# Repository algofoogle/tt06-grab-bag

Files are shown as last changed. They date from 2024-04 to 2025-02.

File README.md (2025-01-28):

 

# Anton's TT06 grab bag

This is a simple analog/mixed-signal project, created from the [TT06 analog template repo](https://github.com/TinyTapeout/tt06-analog-template).

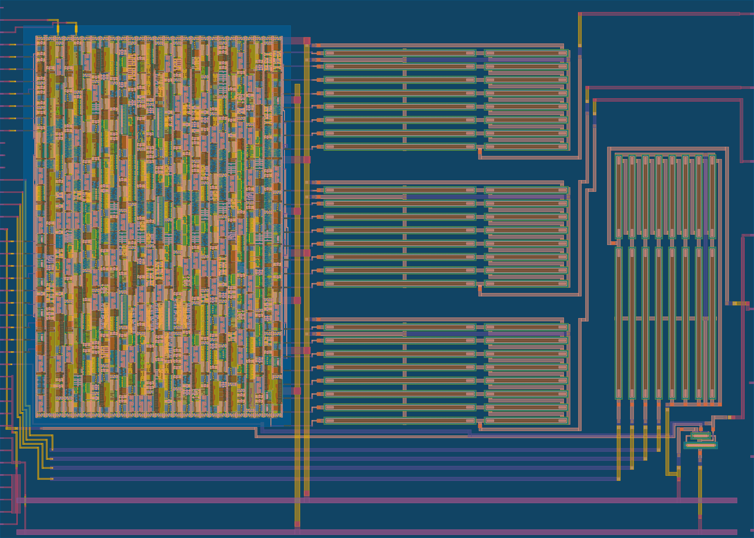
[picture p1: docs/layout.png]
GDS layout render


I was invited to participate in the first round of Matt Venn's Zero to ASIC **Analog Course** beta, and this was the design I ultimately submitted to TT06.

It implements:
*   A digital block that generates a few basic 24b-colour (RGB888) VGA test patterns.
*   Analog RGB outputs (running digital block VGA outputs through 3x 8-bit R2R DACs).
*   An extra 4-bit R2R DAC.
*   A bog-standard CMOS inverter. That was my very first custom layout attempt.

**For much more information, [read the full documentation](docs/info.md)**

See [`pcb/`](./pcb/) for PCBs I've been working on related to this.

# What is Tiny Tapeout?

Tiny Tapeout is an educational project that aims to make it easier and cheaper than ever to get your digital designs manufactured on a real chip.

To learn more and get started, visit https://tinytapeout.com.

# Analog projects

For specifications and instructions, see the [analog specs page](https://tinytapeout.com/specs/analog/).

If you have any questions, please join the [Tiny Tapeout Discord](https://tinytapeout.com/discord) and ask in the `#analog` channel.

# Resources

- [FAQ](https://tinytapeout.com/faq/)
- [Digital design lessons](https://tinytapeout.com/digital_design/)
- [Learn how semiconductors work](https://tinytapeout.com/siliwiz/)
- [Join the community](https://tinytapeout.com/discord)

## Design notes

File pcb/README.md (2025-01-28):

# PCB design files for TT06 Grab Bag

*   [`tt06-vga-opamp/`](./tt06-vga-opamp/) is my original prototyping board that I made for testing tt06-grab-bag. I was originally working on it [here](https://github.com/algofoogle/sandpit/tree/master/opamp/tt06-vga-opamp) (private repo).
*   [`tt06-vga-interposer/`](./tt06-vga-interposer/) is a board I'm working on that sits between the TT06 chip carrier board and the TT06 demo board. It taps the analog signals relevant to this design and buffers them with an OPA3355, and includes a VGA socket.

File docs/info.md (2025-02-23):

<!---
You can also include images in this folder and reference them in the markdown. Each image must be less than
512 kb in size, and the combined size of all images must be less than 1 MB.

NOTE: I've used &#126; instead of actual `~` to avoid a mismatch between GFM and the PDF doc generation
(i.e. GFM sees this character as a strikethrough marker, but the PDF doc generation does not).
Note that `~` while commonly called a tilde is actually the "equivalency sign" (tilde is up high).
Ideally I would use &#x2053 ('swung dash') which is technically probably the correct symbol for
"approximate ranges" but this doesn't work in the PDF generator.
-->

tt06-grab-bag GDS layout showing digital block, 4 DACs, and 1 inverter

## What is this thing?

<!-- <img src="layout-portrait.png" style="float: right; margin-left: 1em;" width="40%" /> -->

A simple analog/mixed-signal project I created in the 1st round of Matt Venn's Zero to ASIC **Analog Course** beta. **This design has been demonstrated to work in silicon.** For silicon test results, see my journal entry: https://algo.org/journal/0226

The design comprises:

*   Simple CMOS inverter. That was my very first custom layout attempt.
*   Digital block generating a few basic 24b-colour (RGB888) VGA test patterns.
*   Analog RGB out (digital block VGA outputs via 3x 8-bit R2R DACs).
*   An extra 4-bit R2R DAC.

## VGA test pattern outputs

The design's *main* purpose is to generate VGA test patterns that were hoped to look as good as these simulations:

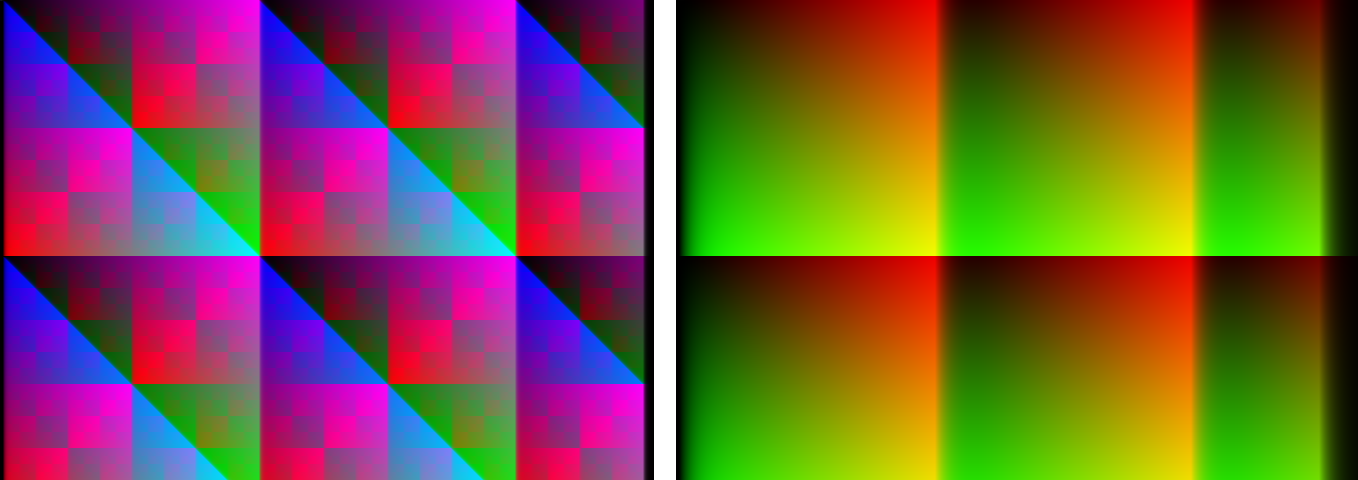
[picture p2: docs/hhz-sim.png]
Simulated VGA outputs, XOR pattern and RAMP pattern


The left-hand pretty pattern is "MODE_XORS" (`ui_in==8'b0011_0000`) while the right-hand gradients pattern is "MODE_RAMP" (`ui_in==8'b0001_0000`).

Notice there is some horizontal smearing (more exaggerated in the right-hand image of the red/green mixes).

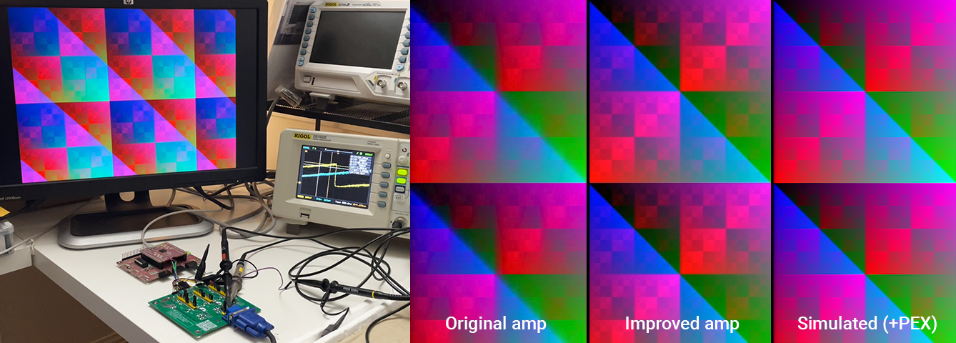
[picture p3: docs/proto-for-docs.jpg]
Real silicon, working, driving a VGA monitor


Actual results from silicon testing (seen above) are pleasing.

## CMOS inverter

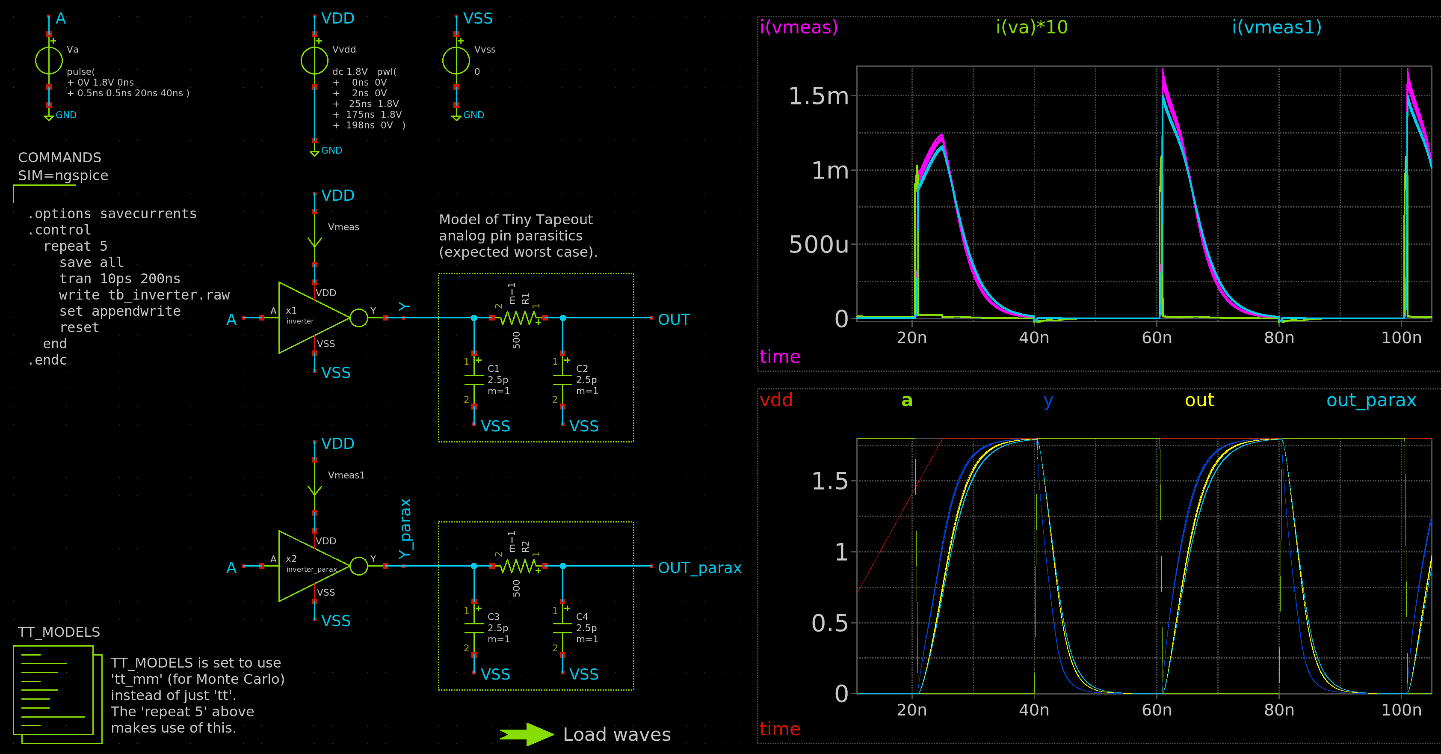
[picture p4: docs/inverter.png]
Xschem simulation of my CMOS inverter


Pretty simple:

*   Its input is `uio_in[7]` (bidir 7).
*   Its output goes to two places: `ua[3]` (analog) and `uio_out[2]` (digital).
*   I'd expect its digital out performance to be better: the TT digital mux has more buffering & less loading than the TT analog mux.

The graphs accompanying the schematics simulate *analog* out is expected to be stable (enough) within 10ns; relatively poor performance characteristic of the TT analog mux loading. I expect bigger transistors could drive this harder and make it faster.

## Extra 4-bit R2R

4th instance of my 8-bit R2R DAC cell grounds the 4 LSB, connecting the 4 MSB to spare bidir inputs (`uio_in[6:4]`) with DAC output via `ua[4]`.

## How it works

TBC!

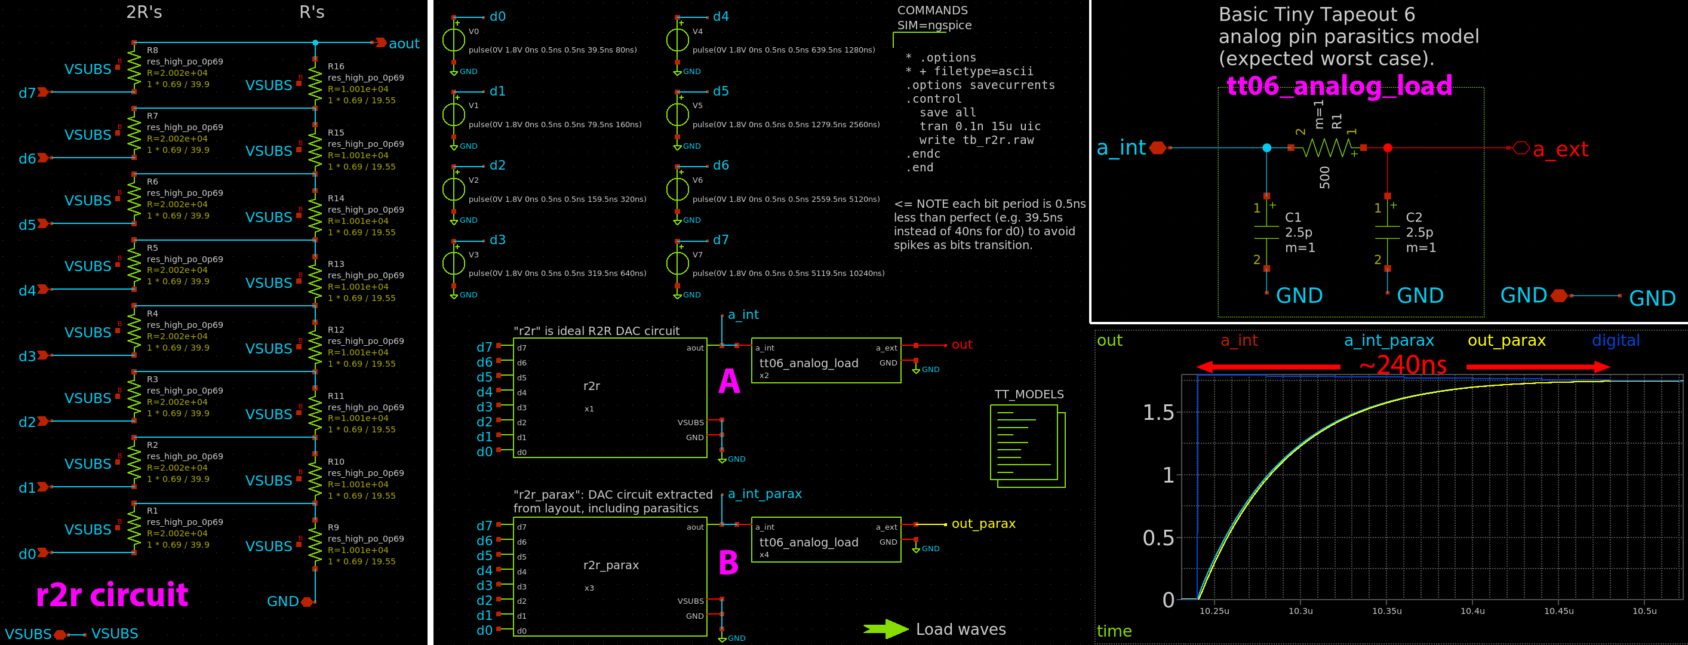
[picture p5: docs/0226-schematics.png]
Combined VGA DACs schematics


The internal R2R DACs for each of the RGB outputs just go directly (unbuffered) to the analog output pins, where they are subject to the loading of the TT06 analog mux (estimated to be about 500&ohm; and 5pF). This combination means their slew rate was expected to be pretty bad (at least by VGA timing standards): On the order of 240&#126;360ns (or 6&#126;9 horizontal pixels) going from 0V to full 1.8V. In the chips I received, it was a little better than that.

In a future design I plan to implement better internal buffering to help mitigate some of the TT analog mux load.

Select from a few simple test patterns in the VGA controller by having different `ui_in` values asserted while coming out of reset. the VGA controller digital block generates 8-bit digital outputs per each of red, green, and blue channels. These go into 3 basic RDACs to generate analog voltage outputs on `ua[2:0]` (`{B,G,R}`) in the range 0-1.8V (probably &#126;10k&ohm; impedance).

## How to test

TBC!

1.  Supply a 25MHz clock
2.  Set `ui_in` to `8'b0001_0000`
3.  Assert reset -- NOTE: I didn't put a synchroniser on it, so it might (?) do a dirty reset -- if that happens, it could be worked around by slowly/manually clocking around the reset pulse, I guess.
4.  With a scope, trigger on the `uo_out[3]` rising edge (VSYNC) and hopefully see `ua[0]` ramp from 0V to 1.8V within 10.24us
5.  With this mode (as selected in step 2 above), `ua[1]` will also ramp, but per line (instead of per pixel), as will `ua[2]` (per frame).
6.  For the pretty XORs pattern, set `ui_in` to `8'b0011_0000` and assert reset again.

NOTE: For actual VGA output, you need the VSYNC and HSYNC signals (connecting them each with a 1k&ohm; resistor in series with their respective VGA cable connection should do). You will almost certainly need some sort of output buffering between this design and a VGA display, because the design outputs a high-impedance (&#126;10k&ohm; but maybe a little worse) 0&#126;1.8V range, while a VGA display expects 0&#126;0.7V at 75&ohm;. See https://algo.org/pcb/tt06i for an example board that covers all this.

Other notes for testing:

*   Digital block's mode selection is asserted via `ui_in` *during reset*
*   For safety, initial test should be done with no analog output loading, and with all of `ui_in` pulled low (which selects pass-thru mode AND ensures all DAC *inputs* internally are low, so hopefully no current).
*   RGB222 digital outputs compatible with the [Tiny VGA PMOD].

## External hardware

This is if you want to see an actual analog VGA display:

*   10MHz-capable (or better; preferably 25MHz) opamps on each of the R, G, B outputs, to both make them into low-impedance (matching 75&ohm; typical VGA termination), and also to level-shift from 0&#126;1.8V to 0&#126;0.7V. See https://algo.org/pcb/tt06i for an example "interposer board" (aka "sandwich board") which uses an OPA3355 video op-amp circuit with VGA connector, and is intended to sit between the TT06 chip's breakout board (aka "carrier") and the TT06 demo board.
*   Optionally the [Tiny VGA PMOD] plugged into the dedicated output port (`uo_out`).

[Tiny VGA PMOD]: https://github.com/mole99/tiny-vga

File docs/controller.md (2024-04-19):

# Controller

## Pinouts

### `ui_in`

*   **DONE:** See detailed info below about reset state

### `uo_out`

These match the Tiny VGA PMOD - See: https://github.com/algofoogle/tt05-vga-spi-rom/blob/9208ed836d03bb5593d383a55a8ddcab464ed9d2/src/tt05_top.v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

0.  **DONE**: `red[7]`
1.  **DONE**: `green[7]`
2.  **DONE**: `blue[7]`
3.  **DONE**: `vsync`
4.  **DONE**: `red[6]`
5.  **DONE**: `green[6]`
6.  **DONE**: `blue[6]`
7.  **DONE**: `hsync`

### `ua`

0.  **DONE:** `red`
1.  **DONE:** `green`
2.  **DONE:** `blue`
3.  **DONE (nil):** (none)
4.  **DONE (nil):** (none)
5.  **DONE**: `Y` (inverter output)

### bidir

0.  **DONE:** OUT: vblank
1.  **DONE:** OUT: hblank
2.  **DONE:** OUT: `Y` (copy of inverter output)
3.  **DONE (nil):** (IN: unused)
4.  **DONE (nil):** (IN: unused)
5.  **DONE (nil):** (IN: unused)
6.  **DONE (nil):** (IN: unused)
7.  **DONE:** IN: `A` (inverter input)

`uio_oe` ties:

0.  **DONE:** *VPWR*
1.  **DONE:** *VPWR*
2.  **DONE:** *VPWR*
3.  **DONE:** VGND
4.  **DONE:** VGND
5.  **DONE:** VGND
6.  **DONE:** VGND
7.  **DONE:** *VPWR*

`uio_out` ties:

3.  **DONE:** VGND
4.  **DONE:** VGND
5.  **DONE:** VGND
6.  **DONE:** VGND
7.  **DONE:** VGND

### Power

*   Controller:
    *   **DONE:** VPWR
    *   **DONE:** VGND
*   DACs:
    *   **DONE:** VGND
    *   **DONE:** VSUBS
*   Inverter:
    *   **DONE:** VPWR (VDD)
    *   **DONE:** VGND (VSS)

## Info

Pin arrangement:

*   North:
    *   TT pin pitch is 3.68um
*   South:
    *   DAC pin pitch is 4um
    *   Insert dummy pins between channels

This is part of an intended mixed-signal design. Not properly implemented yet.

```

Mode selected by ui_in at reset:

Bit 7 specifies VGA timing selection:
    0 = Regular 640x480@59.94Hz from 25.175MHz clock
    1 = 1440x900@60Hz from 26.6175MHz clock

Mode 0: Pass ui_in directly to all 3 DACs:
    76543210
    -000----    Mode
    ------g-    Gate: 0 = ungated; 1 = gated by VGA blanking
    -------r    Registered: 0 = unregistered; 1 = registered

Mode 1: Ramp tests:
    -001----    Mode
    ----dd--    Divider (-1, i.e. 0=div/1, 1=div/2)
    ------pp    Primary:
                0 = red
                1 = green
                2 = blue
                4 = all

Mode 2: Bars test: Ramp interleaved with negative ramp on alternate pixels
    -010----    Mode
    ----dd--    Divider (-1, i.e. 0=div/1, 1=div/2)
    ------pp    Primary:
                0 = red
                1 = green
                2 = blue
                4 = all

Mode 3: XOR patterns
...SEE BELOW...
```

For nice XOR patterns, this Shadertoy code gives an idea of something cool that we can do:

```c
void mainImage( out vec4 fragColor, in vec2 fragCoord )
{
    // Normalized pixel coordinates (from 0 to 1)
    vec2 uv = fragCoord/iResolution.xy;
    
    int t = int(iTime*60.0) & 0xFF;
    int x = int(fragCoord.x) & 0xFF;
    int y = int(fragCoord.y) & 0xFF;
    int ax = (((int(fragCoord.x)+int(iTime*7.5))>>1) & 0xFF);
    int ay = (((int(fragCoord.y)+int(iTime*7.5))>>1) & 0xFF);
    int bx = (((int(fragCoord.x)+int(iTime*15.0))<<0) & 0xFF);
    int by = (((int(fragCoord.y)+int(iTime*30.0))<<0) & 0xFF);
    int cx = (((int(fragCoord.x)+int(iTime*30.0))<<1) & 0xFF);
    int cy = (((int(fragCoord.y)+int(iTime*15.0))<<1) & 0xFF);

    vec3 col;
    if (false) {    
        // Time varying pixel color
        col = vec3(
            float(ax^ay)/256.0,
            float(bx^by)/256.0,
            float(cx^cy)/256.0
        ); //0.5 + 0.5*cos(iTime+uv.xyx+vec3(0,2,4));
    } else {    
        col = vec3(
            float(0xFF&((x>>1)^((y<<0))))/256.0,
            float(0xFF&(x&y))/256.0,
            float(0xFF&(((x-y)&0xFF)+(t&0xFF)/*^(y^x)*/))/256.0
        );
    }

    // Output to screen
    fragColor = vec4(col,1.0);
}
```

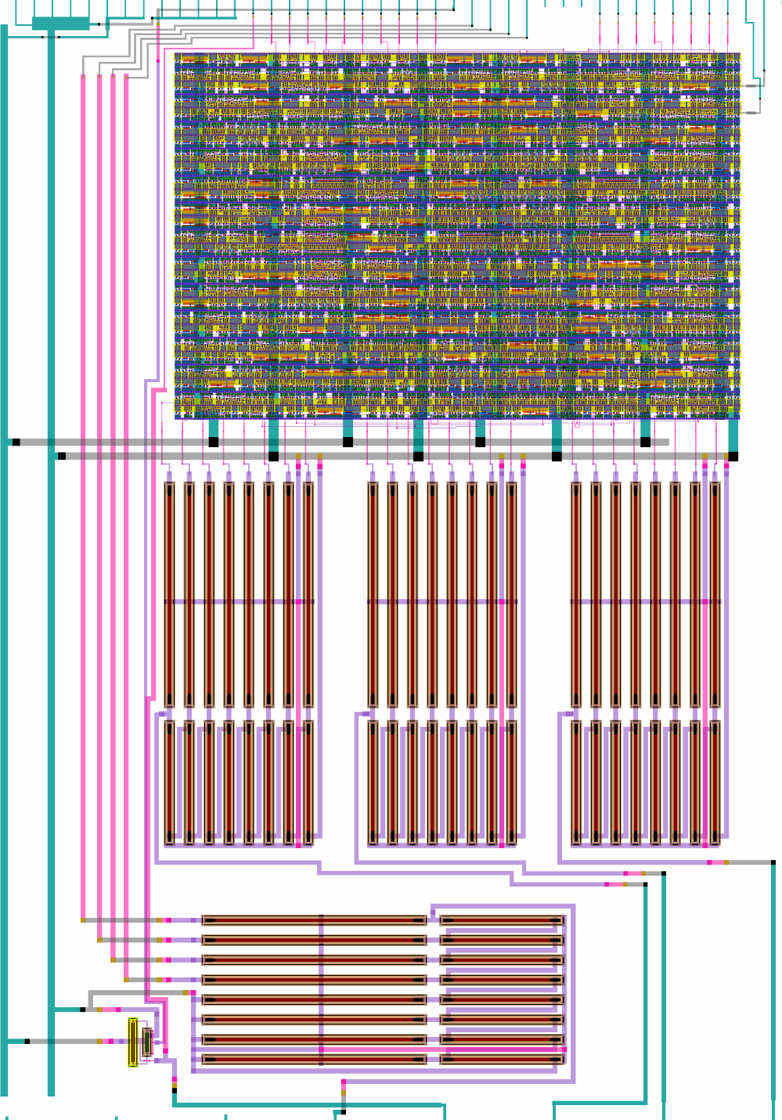
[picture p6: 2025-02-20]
mag/mag-render.png

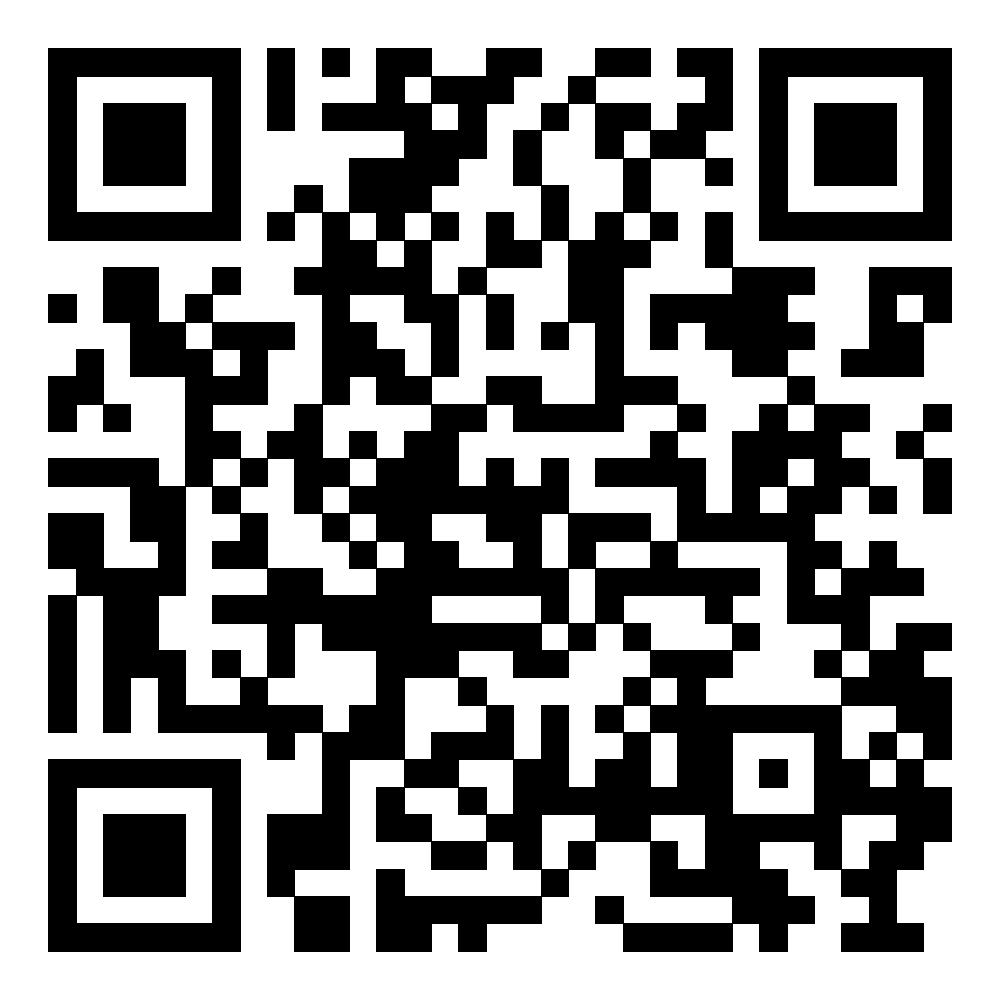
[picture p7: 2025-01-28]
pcb/tt06-vga-opamp/tt06a-qr.png

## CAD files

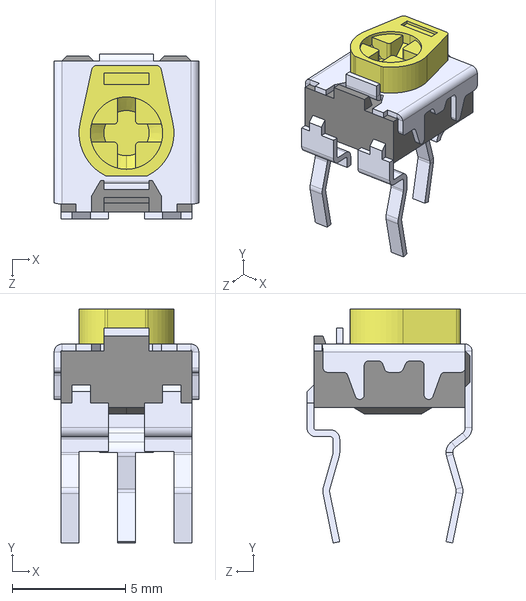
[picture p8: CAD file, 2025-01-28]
pcb/tt06-vga-interposer/3d/EVN_D8AA03B55/EVN-D8AA03B55.step
6.40 x 10.4 x 7.30 mm

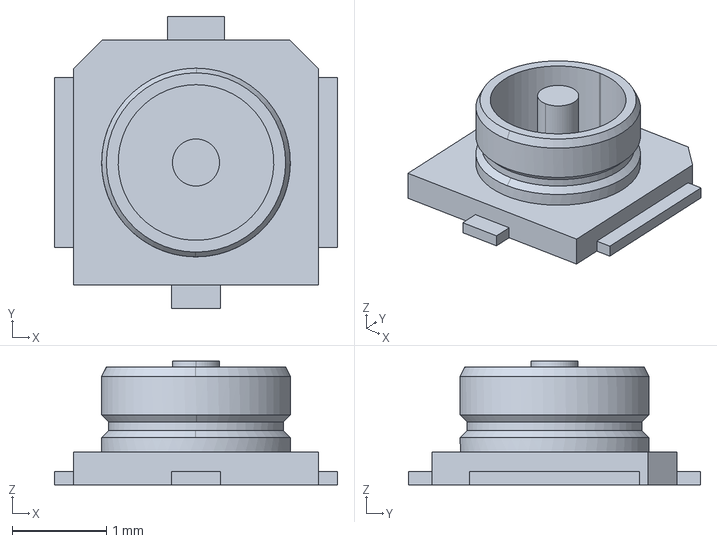
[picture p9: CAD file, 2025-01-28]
pcb/tt06-vga-opamp/U.FL-connector/CONMHF1-SMD-G-T.step
3.00 x 3.10 x 1.31 mm

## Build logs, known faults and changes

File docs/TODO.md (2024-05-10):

*   How to safely probe
*   Input impedance of LM741 and other newer opamps
*   Design PCB base board that fits the carrier -- might need a Pi Pico both for selecting the design, clocking it, and sampling outputs via ADC. Intent of this board is not only for my testing, but also hacking on (if I want to try different core voltage, for example, or doing current limiting) and having an actual VGA output.
*   Pi Pico could clock the design at a slow speed, sample outputs, then gradually speed it up and see how well it performs. Generate images via streaming to PC.
*   Output impedance from the design: Test with a 100k resistor?
*   Simulations:
    *   "Reference image": What it would look like with perfect 24-bit digital output
    *   Just the analog part
    *   Analog part from extraction -- just delete the digital block and re-extract?
    *   Whole extracted layout (using SPICE model for the digital part too) -- will be VERY slow
    *   Cosim
    *   Cosim with an extra Verilog wrapper to provide inputs.

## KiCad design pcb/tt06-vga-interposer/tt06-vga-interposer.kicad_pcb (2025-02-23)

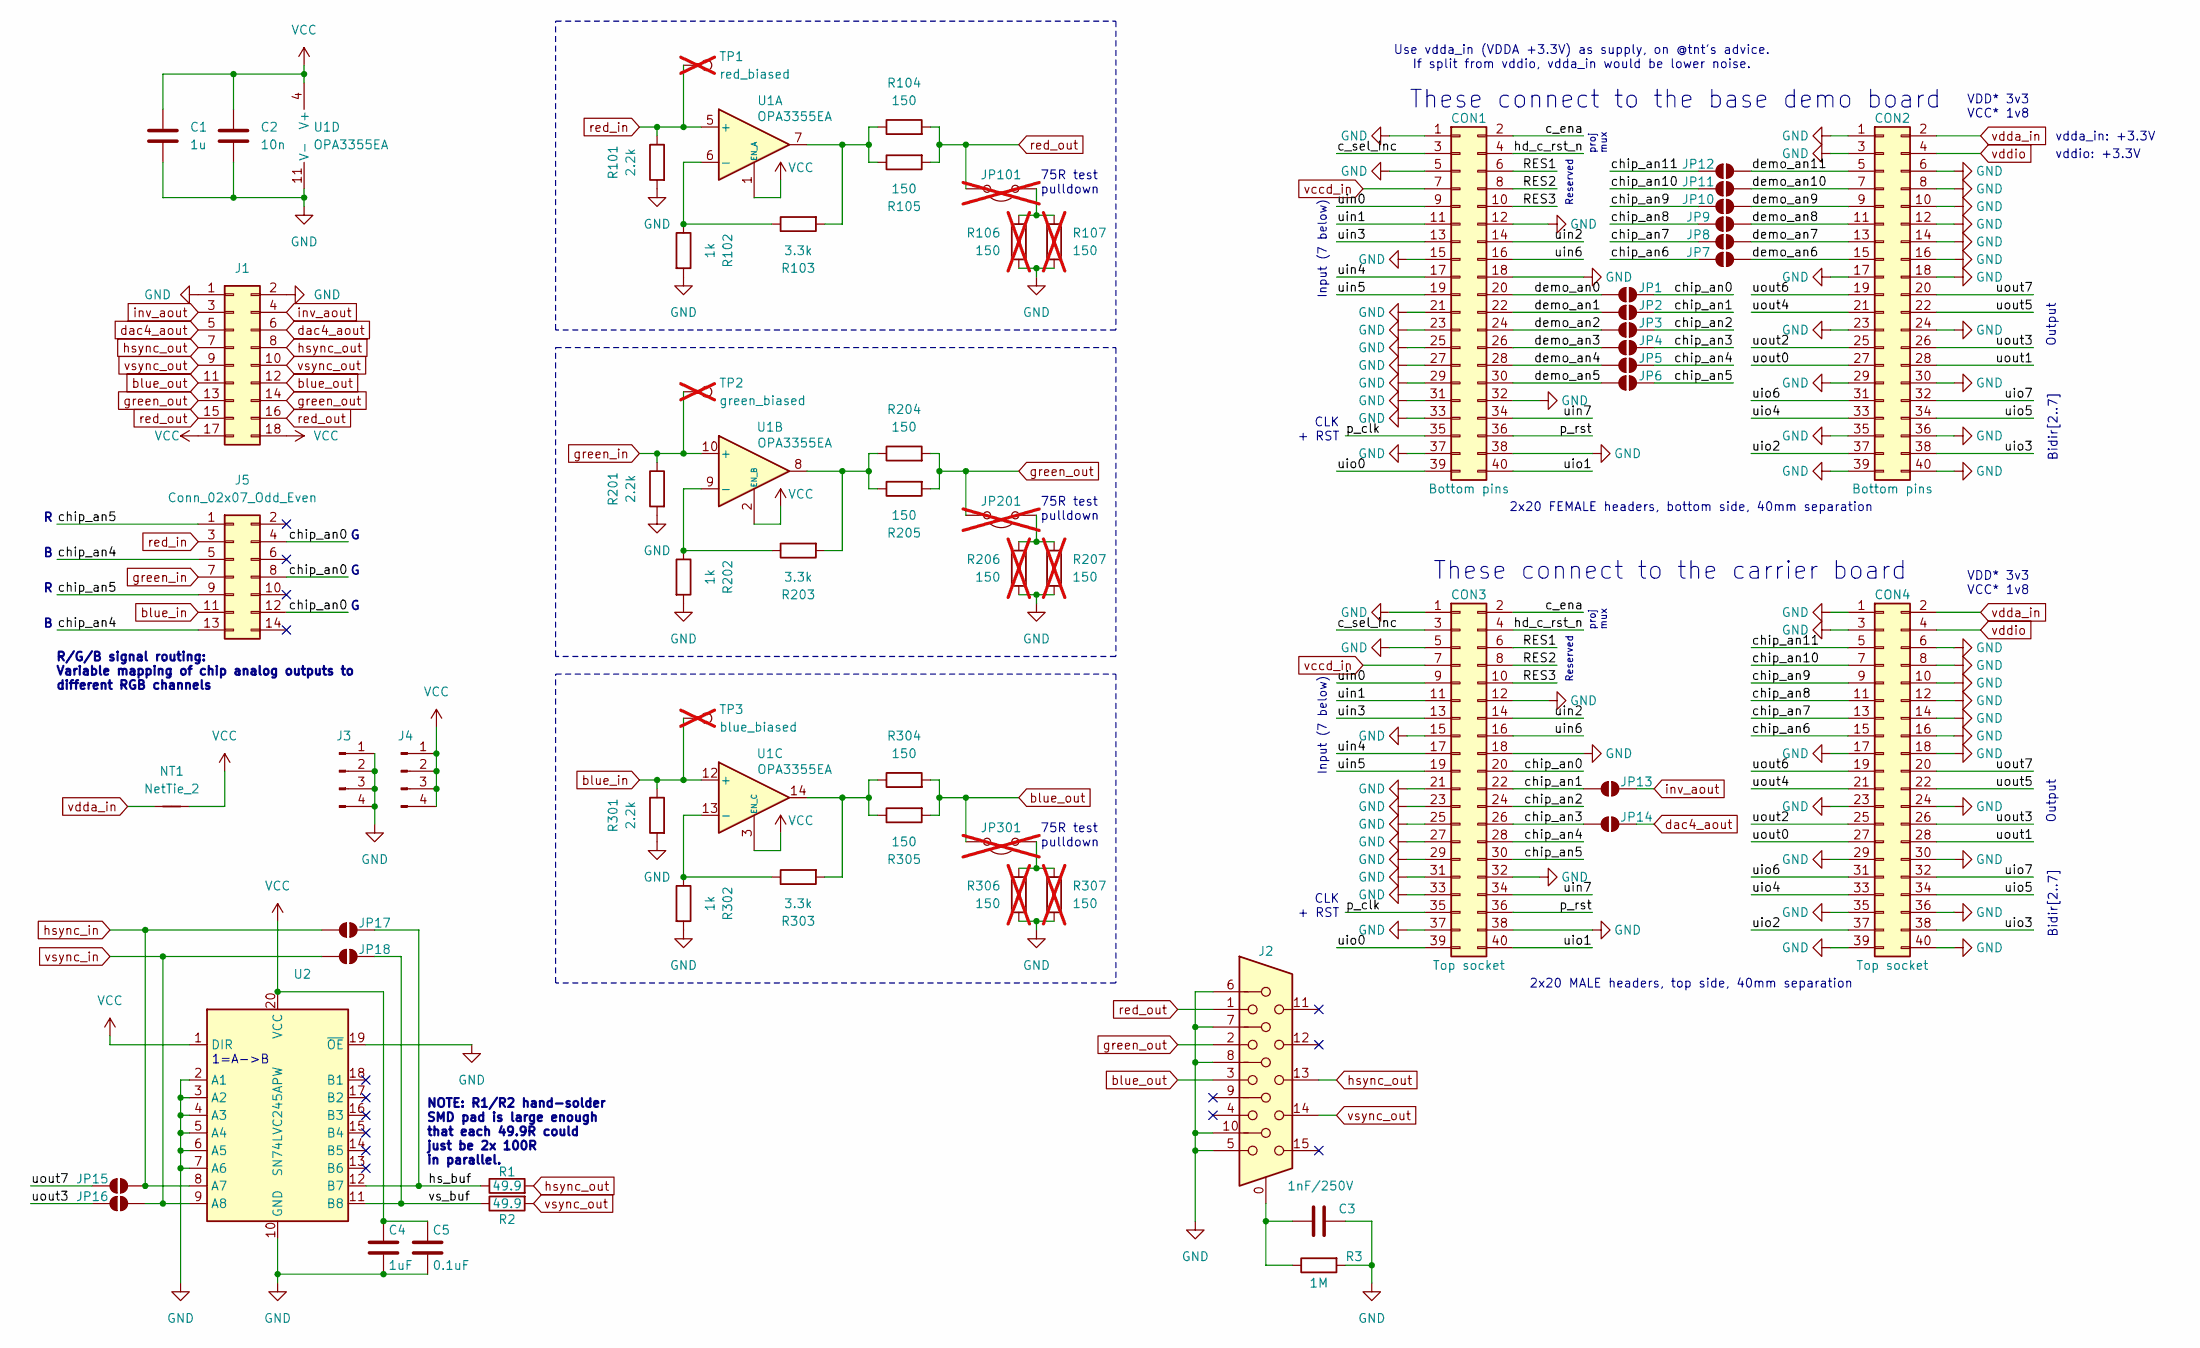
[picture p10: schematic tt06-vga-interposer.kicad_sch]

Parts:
C1: 1u; SMD_Passive_HandSolder_0603_to_1210
C2: 10n; SMD_Passive_HandSolder_0603_to_1210
C3: 1nF/250V; SMD_Passive_HandSolder_0603_to_1210
C4: 1uF; SMD_Passive_HandSolder_0603_to_1210
C5: 0.1uF; SMD_Passive_HandSolder_0603_to_1210
CON1, CON2: Bottom pins; PinSocket_2x20_P2.54mm_Vertical; MPN NPTC202KFMS-RC; DigikeyPN S5690-ND
CON3, CON4: Top socket; PinHeader_2x20_P2.54mm_Vertical; MPN NPTC202KFMS-RC; DigikeyPN S5690-ND
J1: Conn_02x09_Odd_Even; PinHeader_2x09_P2.54mm_Vertical
J2: DE15_Receptacle_HighDensity_MountingHoles; DSUB-15-HD_F_Horz_P2.29x2.54mm_EPO3.03mm_MO4.94mm_STRONG
J3, J4: Conn_01x04_Pin; PinHeader_1x04_P2.54mm_Vertical
J5: Conn_02x07_Odd_Even; PinHeader_2x07_P2.54mm_Horizontal
JP1, JP2, JP3, JP4, JP5, JP6, JP7, JP8, JP9, JP10, JP11, JP12, JP13, JP14, JP15, JP16, JP17, JP18: SolderJumper_2_Open; SolderJumper-2_tiny_nomask
JP101, JP201, JP301: Jumper_2_Open; PinHeader_2x01_P2.54mm_Vertical; not fitted
NT1: NetTie_2; NetTie-2_SMD_Pad0.5mm
R1, R2: 49.9; SMD_Passive_HandSolder_0603_to_1210
R3: 1M; SMD_Passive_HandSolder_0603_to_1210
R101, R201, R301: 2.2k; SMD_Passive_HandSolder_0603_to_1210
R102, R202, R302: 1k; SMD_Passive_HandSolder_0603_to_1210
R103, R203, R303: 3.3k; SMD_Passive_HandSolder_0603_to_1210
R104, R105, R204, R205, R304, R305: 150; SMD_Passive_HandSolder_0603_to_1210
R106, R107, R206, R207, R306, R307: 150; SMD_Passive_HandSolder_0603_to_1210; not fitted
TP1: red_biased; PinHeader_1x01_P2.54mm_Vertical; not fitted
TP2: green_biased; PinHeader_1x01_P2.54mm_Vertical; not fitted
TP3: blue_biased; PinHeader_1x01_P2.54mm_Vertical; not fitted
U1: OPA3355EA; TSSOP-14_4.4x5mm_P0.65mm_HandSolder
U2: SN74LVC245APW; TSSOP-20_4.4x6.5mm_P0.65mm_HandSolder

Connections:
/RES1: CON1.6, CON3.6
/RES2: CON1.8, CON3.8
/RES3: CON1.10, CON3.10
/c_ena: CON1.2, CON3.2
/c_sel_inc: CON1.3, CON3.3
/chip_an0: CON3.20, J5.4, J5.8, J5.12, JP1.2 (B)
/chip_an1: CON3.22, JP2.2 (B), JP13.1 (A)
/chip_an2: CON3.24, JP3.2 (B)
/chip_an3: CON3.26, JP4.2 (B), JP14.1 (A)
/chip_an4: CON3.28, J5.5, J5.13, JP5.2 (B)
/chip_an5: CON3.30, J5.1, J5.9, JP6.2 (B)
/chip_an6: CON4.15, JP7.2 (B)
/chip_an7: CON4.13, JP8.2 (B)
/chip_an8: CON4.11, JP9.2 (B)
/chip_an9: CON4.9, JP10.2 (B)
/chip_an10: CON4.7, JP11.2 (B)
/chip_an11: CON4.5, JP12.2 (B)
/demo_an0: CON1.20, JP1.1 (A)
/demo_an1: CON1.22, JP2.1 (A)
/demo_an2: CON1.24, JP3.1 (A)
/demo_an3: CON1.26, JP4.1 (A)
/demo_an4: CON1.28, JP5.1 (A)
/demo_an5: CON1.30, JP6.1 (A)
/demo_an6: CON2.15, JP7.1 (A)
/demo_an7: CON2.13, JP8.1 (A)
/demo_an8: CON2.11, JP9.1 (A)
/demo_an9: CON2.9, JP10.1 (A)
/demo_an10: CON2.7, JP11.1 (A)
/demo_an11: CON2.5, JP12.1 (A)
/hd_c_rst_n: CON1.4, CON3.4
/hs_buf: JP17.2 (B), R1.1, U2.12 (B7)
/p_clk: CON1.35, CON3.35
/p_rst: CON1.36, CON3.36
/uin0: CON1.9, CON3.9
/uin1: CON1.11, CON3.11
/uin2: CON1.14, CON3.14
/uin3: CON1.13, CON3.13
/uin4: CON1.17, CON3.17
/uin5: CON1.19, CON3.19
/uin6: CON1.16, CON3.16
/uin7: CON1.34, CON3.34
/uio0: CON1.39, CON3.39
/uio1: CON1.40, CON3.40
/uio2: CON2.37, CON4.37
/uio3: CON2.38, CON4.38
/uio4: CON2.33, CON4.33
/uio5: CON2.34, CON4.34
/uio6: CON2.31, CON4.31
/uio7: CON2.32, CON4.32
/uout0: CON2.27, CON4.27
/uout1: CON2.28, CON4.28
/uout2: CON2.25, CON4.25
/uout3: CON2.26, CON4.26, JP16.2 (B)
/uout4: CON2.21, CON4.21
/uout5: CON2.22, CON4.22
/uout6: CON2.19, CON4.19
/uout7: CON2.20, CON4.20, JP15.2 (B)
/vs_buf: JP18.2 (B), R2.1, U2.11 (B8)
GND: C1.2, C2.2, C3.2, C4.2, C5.2, CON1.1, CON1.5, CON1.12, CON1.15, CON1.18, CON1.21, CON1.23, CON1.25, CON1.27, CON1.29, CON1.31, CON1.32, CON1.33, CON1.37, CON1.38, CON2.1, CON2.3, CON2.6, CON2.8, CON2.10, CON2.12, CON2.14, CON2.16, CON2.17, CON2.18, CON2.23, CON2.24, CON2.29, CON2.30, CON2.35, CON2.36, CON2.39, CON2.40, CON3.1, CON3.5, CON3.12, CON3.15, CON3.18, CON3.21, CON3.23, CON3.25, CON3.27, CON3.29, CON3.31, CON3.32, CON3.33, CON3.37, CON3.38, CON4.1, CON4.3, CON4.6, CON4.8, CON4.10, CON4.12, CON4.14, CON4.16, CON4.17, CON4.18, CON4.23, CON4.24, CON4.29, CON4.30, CON4.35, CON4.36, CON4.39, CON4.40, J1.1, J1.2, J2.5, J2.6, J2.7, J2.8, J2.10, J3.1, J3.2, J3.3, J3.4, R3.2, R101.2, R102.2, R106.1, R107.1, R201.2, R202.2, R206.1, R207.1, R301.2, R302.2, R306.1, R307.1, U1.11 (V-), U2.2 (A1), U2.3 (A2), U2.4 (A3), U2.5 (A4), U2.6 (A5), U2.7 (A6), U2.10 (GND), U2.19 (~OE)
unnamed: C3.1, J2.0, R3.1
unnamed: JP101.2 (B), R106.2, R107.2
unnamed: JP201.2 (B), R206.2, R207.2
unnamed: JP301.2 (B), R306.2, R307.2
unnamed: R103.2, R104.1, R105.1, U1.7
unnamed: R203.2, R204.1, R205.1, U1.8
unnamed: R303.2, R304.1, R305.1, U1.14
unnamed: R102.1, R103.1, U1.6 (-)
unnamed: R202.1, R203.1, U1.9 (-)
unnamed: R302.1, R303.1, U1.13 (-)
VCC: C1.1, C2.1, C4.1, C5.1, J1.17, J1.18, J4.1, J4.2, J4.3, J4.4, NT1.1, U1.1 (EN_A), U1.2 (EN_B), U1.3 (EN_C), U1.4 (V+), U2.1 (DIR), U2.20 (VCC)
blue_in: J5.11, R301.1, TP3.1, U1.12 (+)
blue_out: J1.11, J1.12, J2.3, JP301.1 (A), R304.2, R305.2
dac4_aout: J1.5, J1.6, JP14.2 (B)
green_in: J5.7, R201.1, TP2.1, U1.10 (+)
green_out: J1.13, J1.14, J2.2, JP201.1 (A), R204.2, R205.2
hsync_in: JP15.1 (A), JP17.1 (A), U2.8 (A7)
hsync_out: J1.7, J1.8, J2.13, R1.2
inv_aout: J1.3, J1.4, JP13.2 (B)
red_in: J5.3, R101.1, TP1.1, U1.5 (+)
red_out: J1.15, J1.16, J2.1, JP101.1 (A), R104.2, R105.2
vccd_in: CON1.7, CON3.7
vdda_in: CON2.2, CON4.2, NT1.2
vddio: CON2.4, CON4.4
vsync_in: JP16.1 (A), JP18.1 (A), U2.9 (A8)
vsync_out: J1.9, J1.10, J2.14, R2.2

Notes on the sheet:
Output
proj mux
Use vdda_in (VDDA +3.3V) as supply, on @tnt's advice. If split from vddio, vdda_in would be lower noise.
VDD* 3v3 VCC* 1v8
vdda_in: +3.3V
Reserved
75R test pulldown
These connect to the carrier board
2x20 FEMALE headers, bottom side, 40mm separation
Input (7 below)
2x20 MALE headers, top side, 40mm separation
vddio: +3.3V
R/G/B signal routing: Variable mapping of chip analog outputs to different RGB channels
NOTE: R1/R2 hand-solder SMD pad is large enough that each 49.9R could just be 2x 100R in parallel.
Bidir[2..7]
These connect to the base demo board
1=A->B
CLK + RST

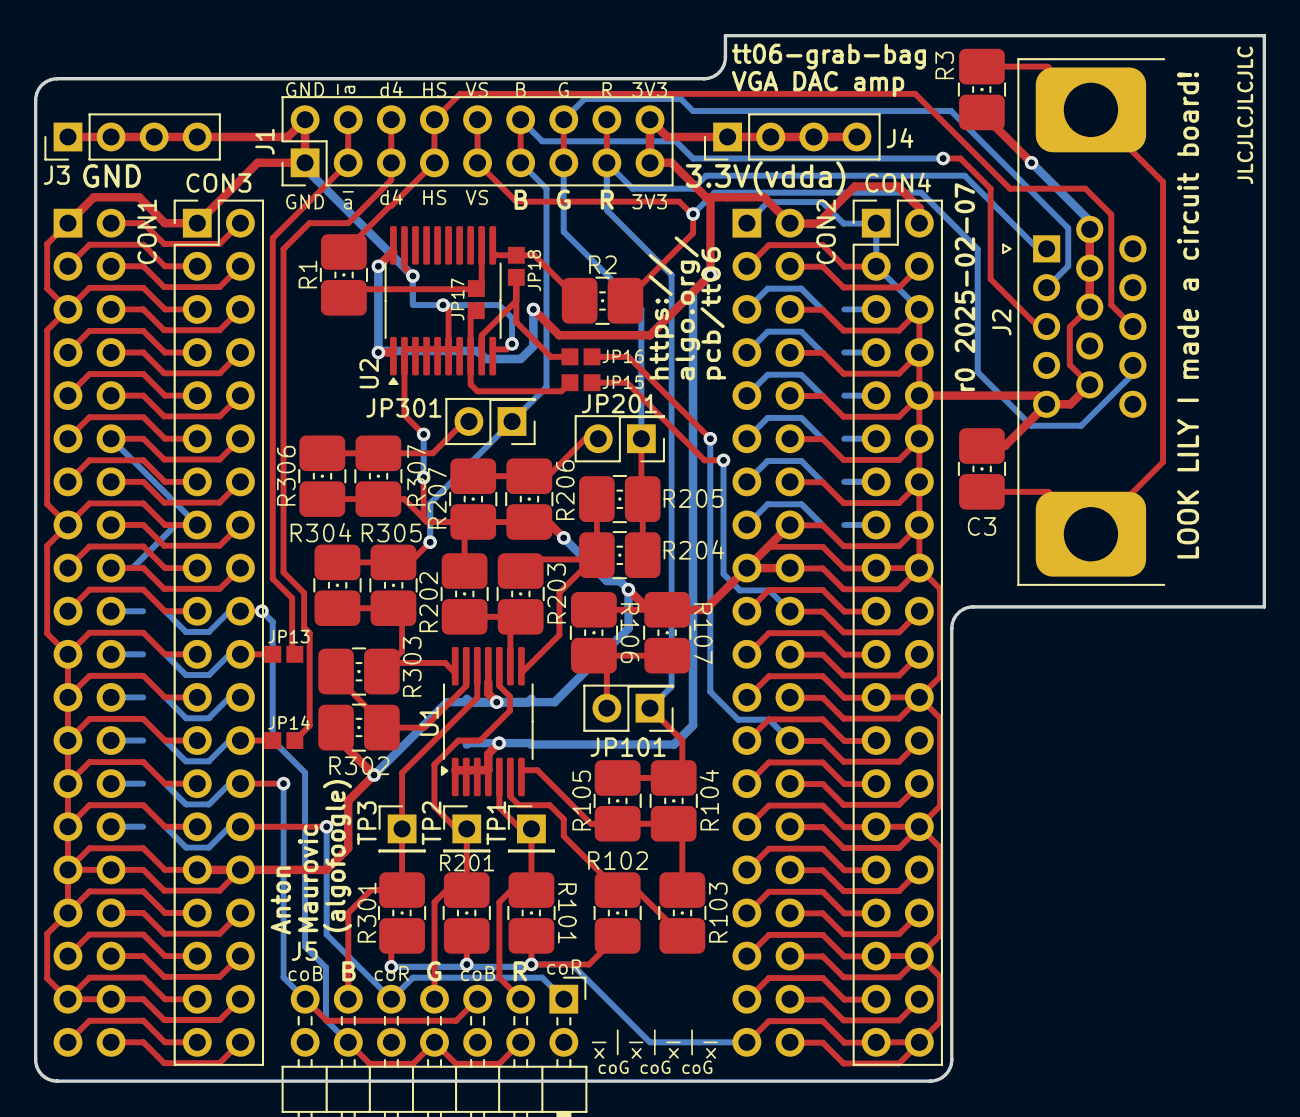
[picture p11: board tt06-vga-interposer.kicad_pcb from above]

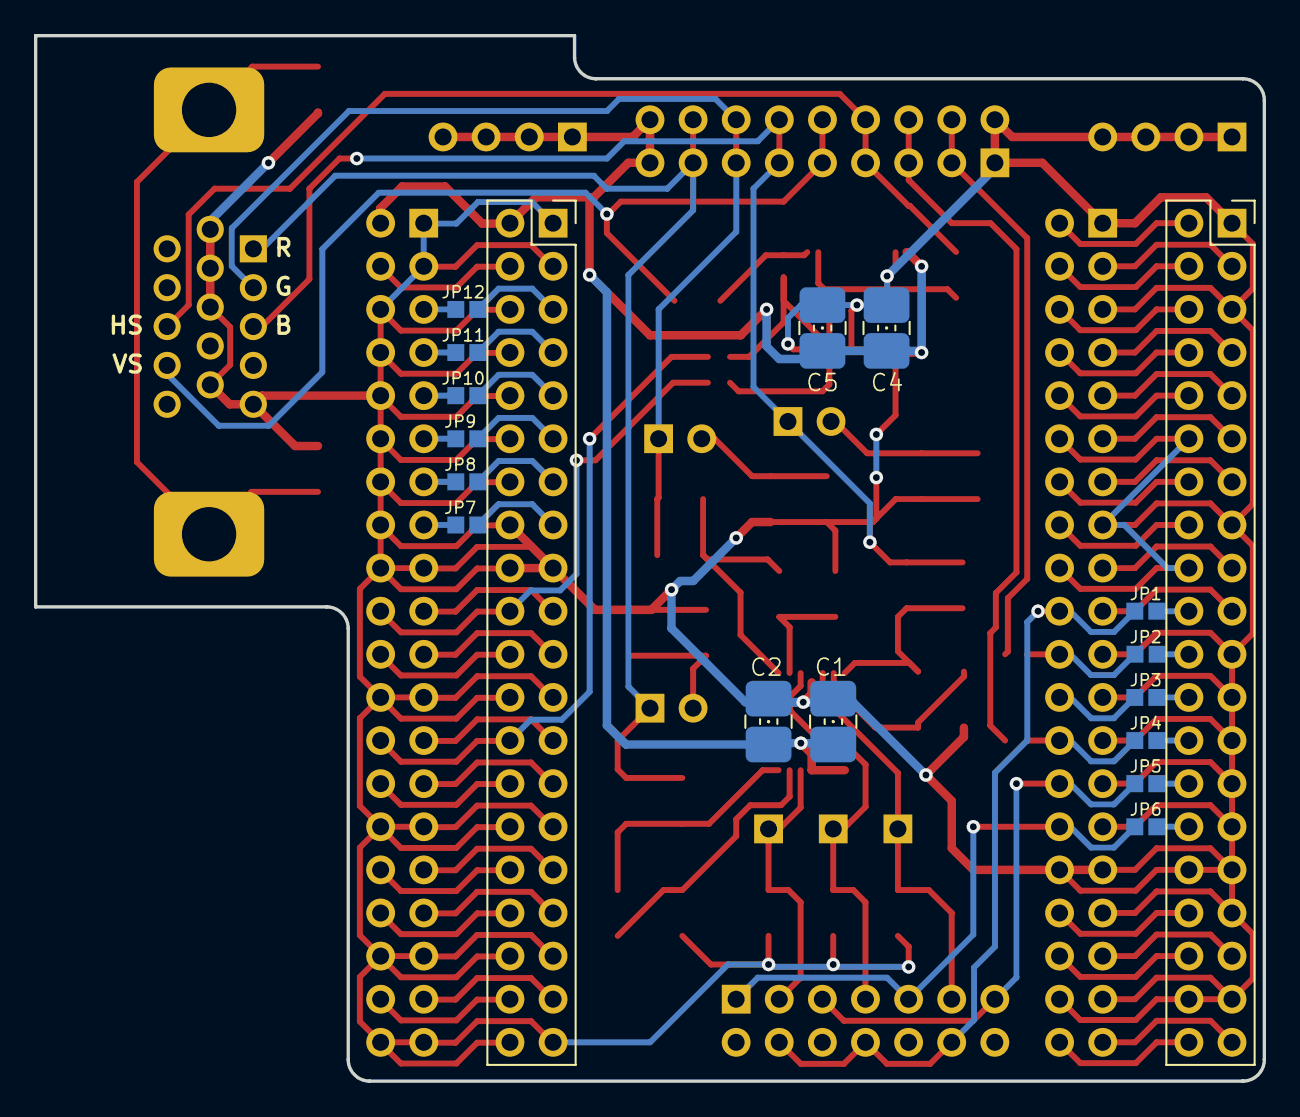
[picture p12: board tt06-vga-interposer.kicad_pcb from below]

Board: 2 copper layers, 72.4 x 61.6 mm, 65 parts (18 on the bottom side), 85 nets.

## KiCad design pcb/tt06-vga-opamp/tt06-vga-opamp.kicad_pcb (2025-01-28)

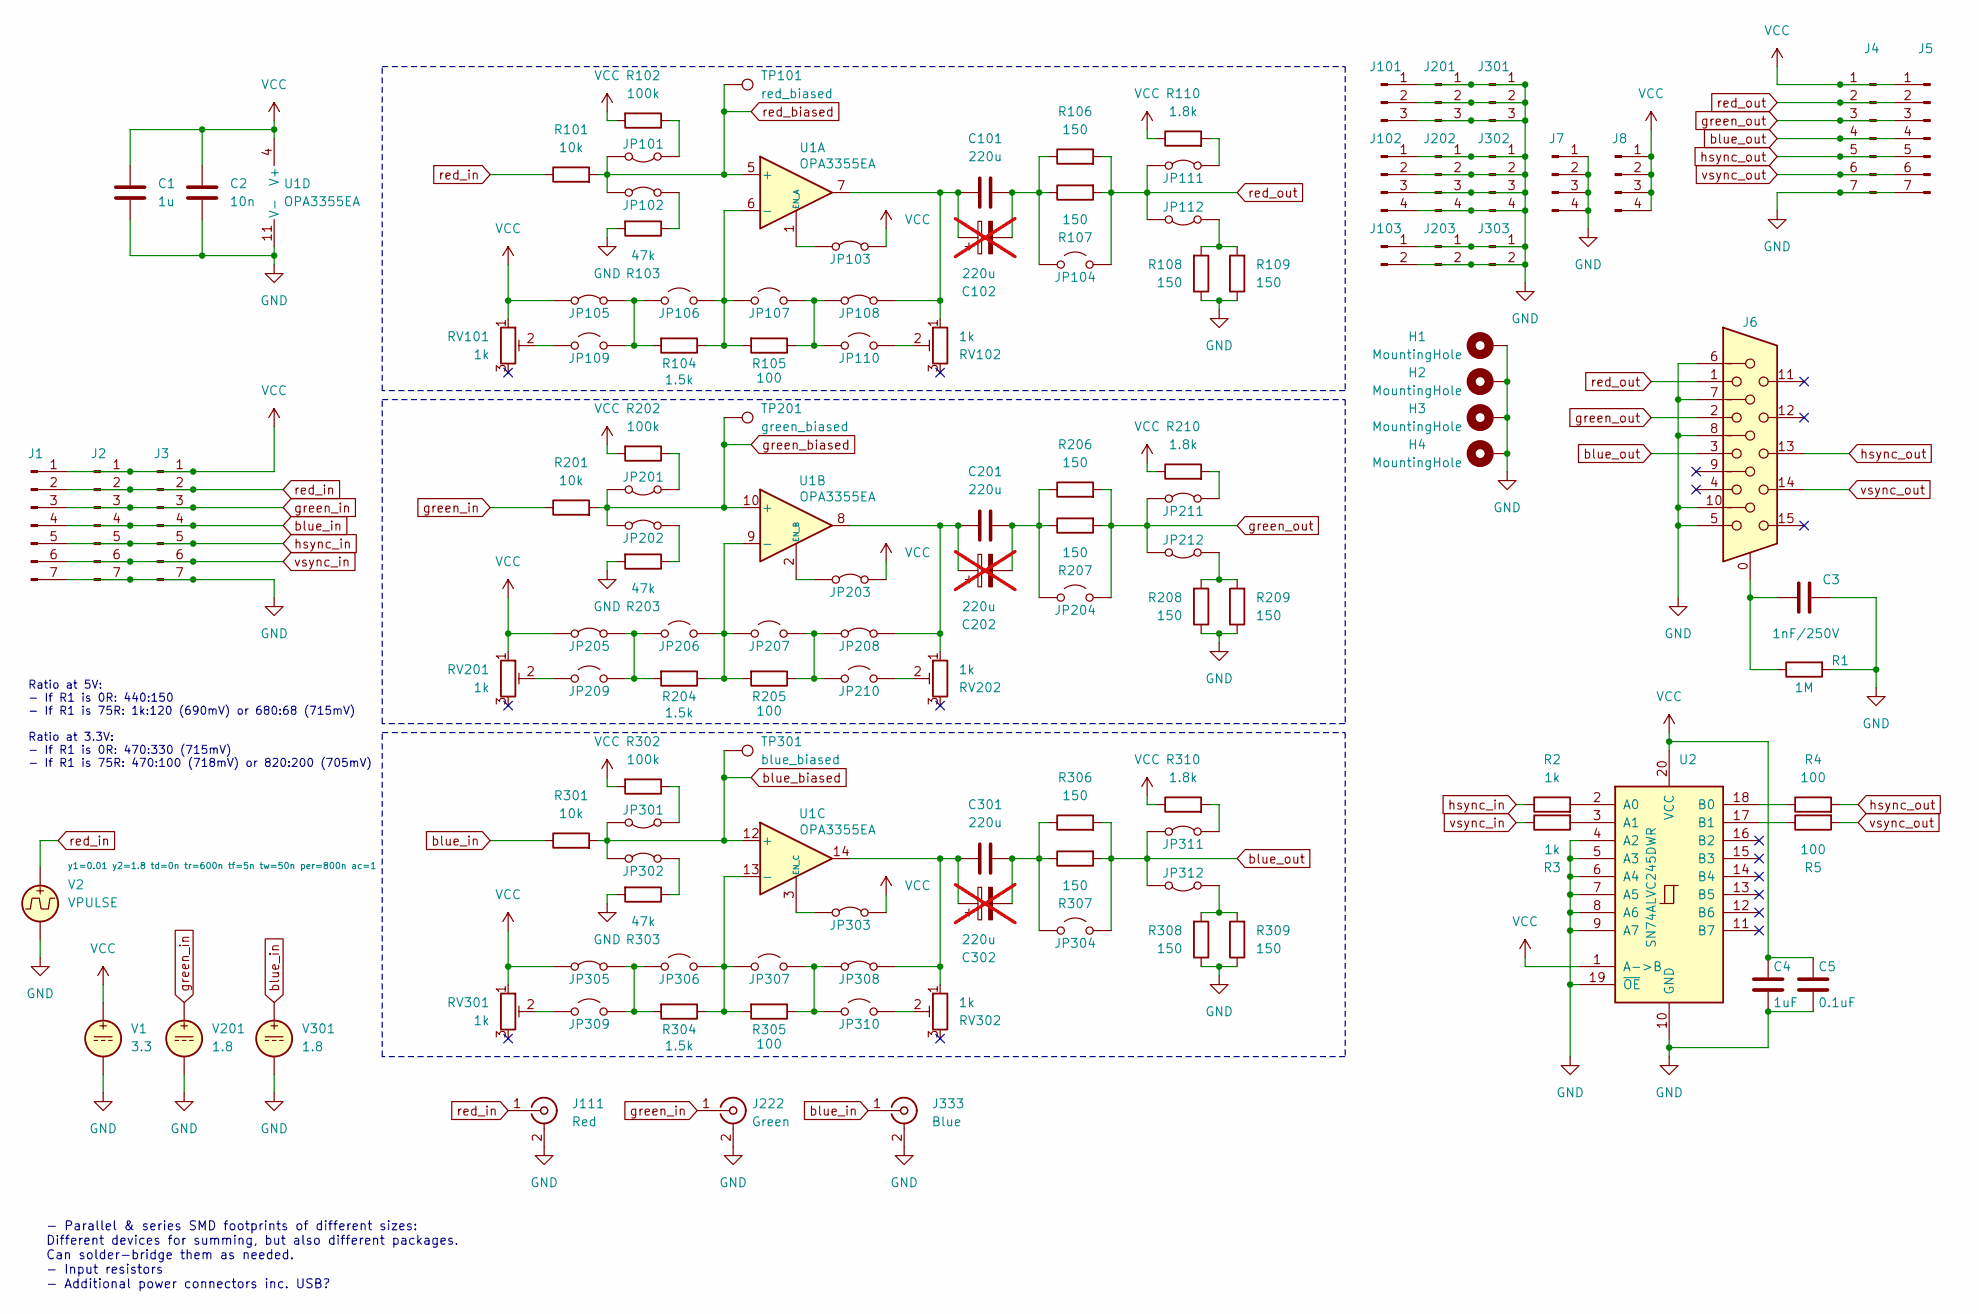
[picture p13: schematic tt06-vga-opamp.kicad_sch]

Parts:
C1: 1u; SMD_Passive_HandSolder_0603_to_1210
C2: 10n; SMD_Passive_HandSolder_0603_to_1210
C3: 1nF/250V; SMD_Passive_HandSolder_0603_to_1210
C4: 1uF; SMD_Passive_HandSolder_0603_to_1210
C5: 0.1uF; SMD_Passive_HandSolder_0603_to_1210
C101, C201, C301: 220u; SMD_Passive_HandSolder_0603_to_1210
C102, C202, C302: 220u; CP_Radial_D10.0mm_P2.50mm_P5.00mm; not fitted
H1, H2, H3, H4: MountingHole; MountingHole_4.3mm_M4_DIN965_Pad
J1, J2, J3, J4, J5: Conn_01x07_Pin; PinHeader_1x07_P2.54mm_Vertical
J6: DE15_Receptacle_HighDensity_MountingHoles; DSUB-15-HD_F_Horz_P2.29x2.54mm_EPO3.03mm_MO4.94mm_STRONG
J7, J8, J102, J202, J302: Conn_01x04_Pin; PinHeader_1x04_P2.54mm_Vertical
J101, J201, J301: Conn_01x03_Pin; PinHeader_1x03_P2.54mm_Vertical
J103, J203, J303: Conn_01x02_Pin; PinHeader_1x02_P2.54mm_Vertical
J111: Red; LINX_CONMHF1-SMD-G-T_U.FL_HandSolder
J222: Green; LINX_CONMHF1-SMD-G-T_U.FL_HandSolder
J333: Blue; LINX_CONMHF1-SMD-G-T_U.FL_HandSolder
JP101, JP102, JP103, JP105, JP108, JP111, JP112, JP201, JP202, JP203, JP205, JP208, JP211, JP212, JP301, JP302, JP303, JP305, JP308, JP311, JP312: Jumper_2_Bridged; PinHeader_1x02_P2.54mm_Vertical
JP104, JP106, JP107, JP109, JP110, JP204, JP206, JP207, JP209, JP210, JP304, JP306, JP307, JP309, JP310: Jumper_2_Open; PinHeader_1x02_P2.54mm_Vertical
R1: 1M; SMD_Passive_HandSolder_0603_to_1210
R2, R3: 1k; SMD_Passive_HandSolder_0603_to_1210
R4, R5, R105, R205, R305: 100; SMD_Passive_HandSolder_0603_to_1210
R101, R201, R301: 10k; SMD_Passive_HandSolder_0603_to_1210
R102, R202, R302: 100k; SMD_Passive_HandSolder_0603_to_1210
R103, R203, R303: 47k; SMD_Passive_HandSolder_0603_to_1210
R104, R204, R304: 1.5k; SMD_Passive_HandSolder_0603_to_1210
R106, R107, R108, R109, R206, R207, R208, R209, R306, R307, R308, R309: 150; SMD_Passive_HandSolder_0603_to_1210
R110, R210, R310: 1.8k; SMD_Passive_HandSolder_0603_to_1210
RV101, RV102, RV201, RV202, RV301, RV302: 1k; Potentiometer_Runtron_RM-065_Vertical
TP101: red_biased; PinHeader_1x01_P2.54mm_Vertical
TP201: green_biased; PinHeader_1x01_P2.54mm_Vertical
TP301: blue_biased; PinHeader_1x01_P2.54mm_Vertical
U1: OPA3355EA; TSSOP-14_4.4x5mm_P0.65mm_HandSolder
U2: SN74ALVC245DWR; SOIC-20W_7.5x12.8mm_P1.27mm
V1: 3.3
V2: VPULSE
V201, V301: 1.8

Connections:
GND: C1.2, C2.2, C3.2, C4.2, C5.2, H1.1, H2.1, H3.1, H4.1, J1.7, J2.7, J3.7, J4.7, J5.7, J6.5, J6.6, J6.7, J6.8, J6.10, J7.1, J7.2, J7.3, J7.4, J101.1, J101.2, J101.3, J102.1, J102.2, J102.3, J102.4, J103.1, J103.2, J111.2 (Ext), J201.1, J201.2, J201.3, J202.1, J202.2, J202.3, J202.4, J203.1, J203.2, J222.2 (Ext), J301.1, J301.2, J301.3, J302.1, J302.2, J302.3, J302.4, J303.1, J303.2, J333.2 (Ext), R1.2, R103.2, R108.1, R109.1, R203.2, R208.1, R209.1, R303.2, R308.1, R309.1, U1.11 (V-), U2.4 (A2), U2.5 (A3), U2.6 (A4), U2.7 (A5), U2.8 (A6), U2.9 (A7), U2.10 (GND), U2.19 (~OE), V1.2, V2.2, V201.2, V301.2
unnamed: C3.1, J6.0, R1.1
unnamed: JP101.2 (B), R102.1
unnamed: JP102.2 (B), R103.1
unnamed: JP103.1 (A), U1.1 (EN_A)
unnamed: C101.2, C102.2, JP104.1 (A), R106.1, R107.1
unnamed: JP105.2 (B), JP106.1 (A), JP109.2 (B), R104.2
unnamed: JP106.2 (B), JP107.1 (A), R104.1, R105.2, U1.6 (-)
unnamed: JP107.2 (B), JP108.1 (A), JP110.1 (A), R105.1
unnamed: C101.1, C102.1, JP108.2 (B), RV102.1, U1.7
unnamed: JP109.1 (A), RV101.2
unnamed: JP110.2 (B), RV102.2
unnamed: JP111.2 (B), R110.2
unnamed: JP112.1 (A), R108.2, R109.2
unnamed: JP201.2 (B), R202.1
unnamed: JP202.2 (B), R203.1
unnamed: JP203.1 (A), U1.2 (EN_B)
unnamed: C201.2, C202.2, JP204.1 (A), R206.1, R207.1
unnamed: JP205.2 (B), JP206.1 (A), JP209.2 (B), R204.2
unnamed: JP206.2 (B), JP207.1 (A), R204.1, R205.2, U1.9 (-)
unnamed: JP207.2 (B), JP208.1 (A), JP210.1 (A), R205.1
unnamed: C201.1, C202.1, JP208.2 (B), RV202.1, U1.8
unnamed: JP209.1 (A), RV201.2
unnamed: JP210.2 (B), RV202.2
unnamed: JP211.2 (B), R210.2
unnamed: JP212.1 (A), R208.2, R209.2
unnamed: JP301.2 (B), R302.1
unnamed: JP302.2 (B), R303.1
unnamed: JP303.1 (A), U1.3 (EN_C)
unnamed: C301.2, C302.2, JP304.1 (A), R306.1, R307.1
unnamed: JP305.2 (B), JP306.1 (A), JP309.2 (B), R304.2
unnamed: JP306.2 (B), JP307.1 (A), R304.1, R305.2, U1.13 (-)
unnamed: JP307.2 (B), JP308.1 (A), JP310.1 (A), R305.1
unnamed: C301.1, C302.1, JP308.2 (B), RV302.1, U1.14
unnamed: JP309.1 (A), RV301.2
unnamed: JP310.2 (B), RV302.2
unnamed: JP311.2 (B), R310.2
unnamed: JP312.1 (A), R308.2, R309.2
unnamed: R2.2, U2.2 (A0)
unnamed: R3.2, U2.3 (A1)
unnamed: R4.1, U2.18 (B0)
unnamed: R5.1, U2.17 (B1)
VCC: C1.1, C2.1, C4.1, C5.1, J1.1, J2.1, J3.1, J4.1, J5.1, J8.1, J8.2, J8.3, J8.4, JP103.2 (B), JP105.1 (A), JP203.2 (B), JP205.1 (A), JP303.2 (B), JP305.1 (A), R102.2, R110.1, R202.2, R210.1, R302.2, R310.1, RV101.1, RV201.1, RV301.1, U1.4 (V+), U2.1 (A->B), U2.20 (VCC), V1.1
blue_biased: JP301.1 (A), JP302.1 (A), R301.2, TP301.1, U1.12 (+)
blue_in: J1.4, J2.4, J3.4, J333.1 (In), R301.1, V301.1
blue_out: J4.4, J5.4, J6.3, JP304.2 (B), JP311.1 (A), JP312.2 (B), R306.2, R307.2
green_biased: JP201.1 (A), JP202.1 (A), R201.2, TP201.1, U1.10 (+)
green_in: J1.3, J2.3, J3.3, J222.1 (In), R201.1, V201.1
green_out: J4.3, J5.3, J6.2, JP204.2 (B), JP211.1 (A), JP212.2 (B), R206.2, R207.2
hsync_in: J1.5, J2.5, J3.5, R2.1
hsync_out: J4.5, J5.5, J6.13, R4.2
red_biased: JP101.1 (A), JP102.1 (A), R101.2, TP101.1, U1.5 (+)
red_in: J1.2, J2.2, J3.2, J111.1 (In), R101.1, V2.1
red_out: J4.2, J5.2, J6.1, JP104.2 (B), JP111.1 (A), JP112.2 (B), R106.2, R107.2
vsync_in: J1.6, J2.6, J3.6, R3.1
vsync_out: J4.6, J5.6, J6.14, R5.2

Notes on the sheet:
- Parallel & series SMD footprints of different sizes: Different devices for summing, but also different packages. Can solder-bridge them as needed. - Input resistors - Additional power connectors inc. USB?
Ratio at 5V: - If R1 is 0R: 440:150 - If R1 is 75R: 1k:120 (690mV) or 680:68 (715mV) Ratio at 3.3V: - If R1 is 0R: 470:330 (715mV) - If R1 is 75R: 470:100 (718mV) or 820:200 (705mV)

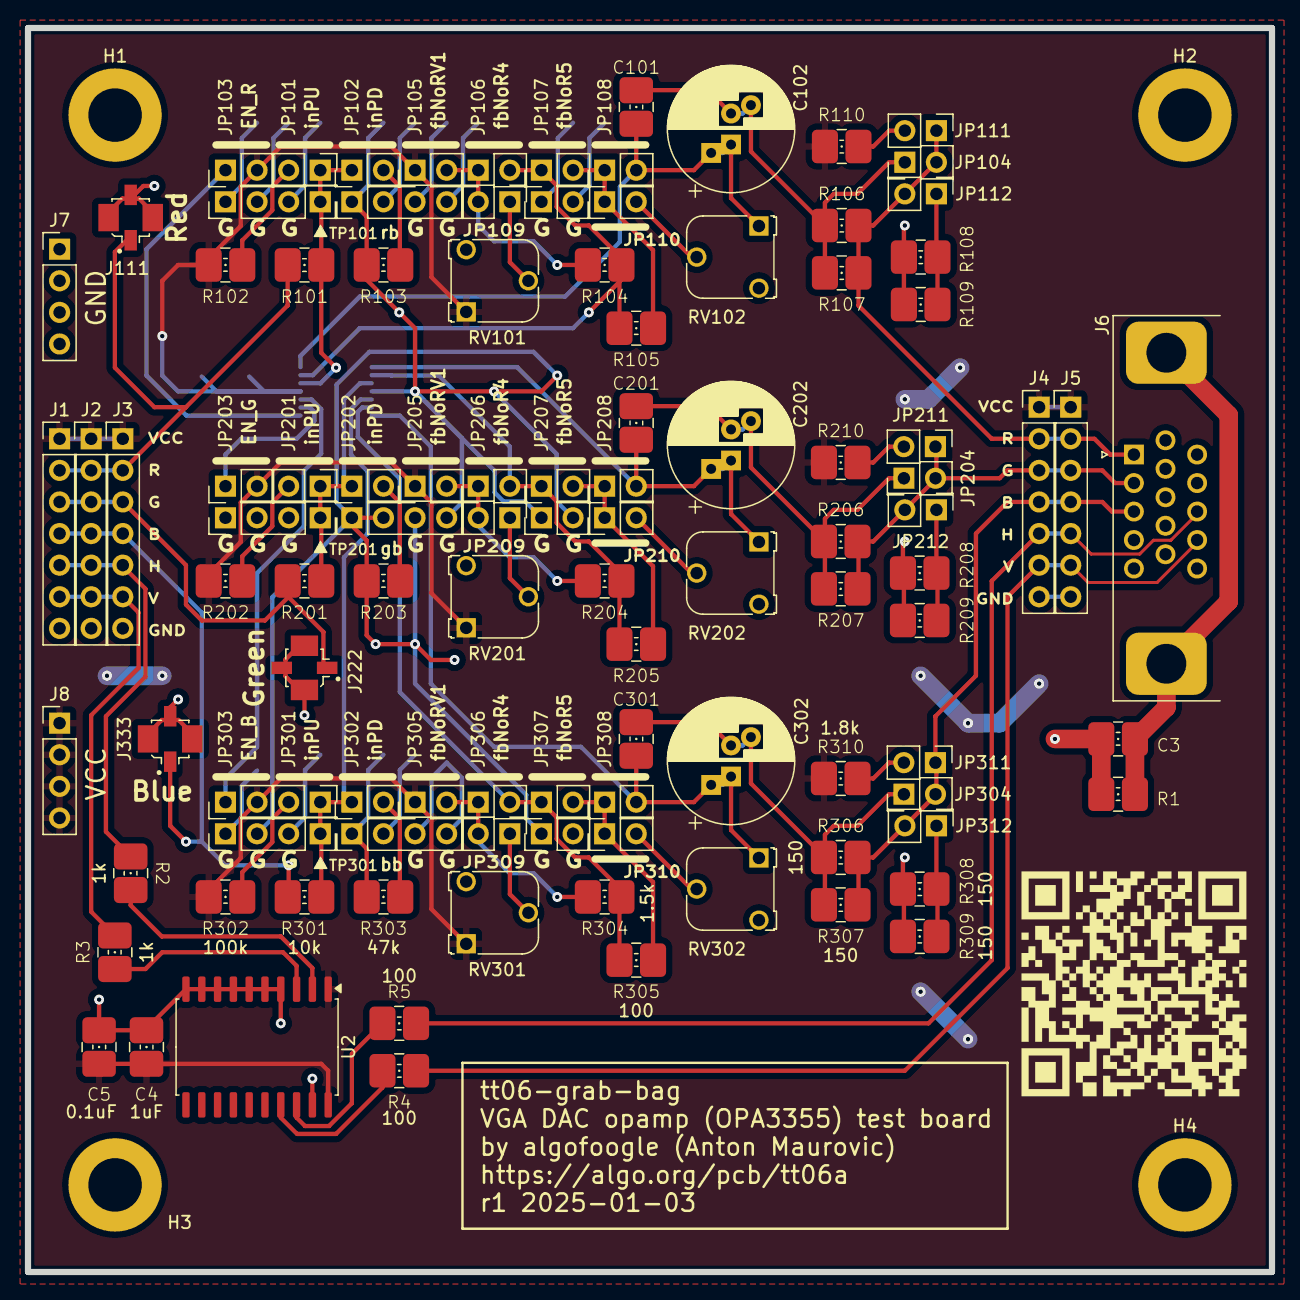
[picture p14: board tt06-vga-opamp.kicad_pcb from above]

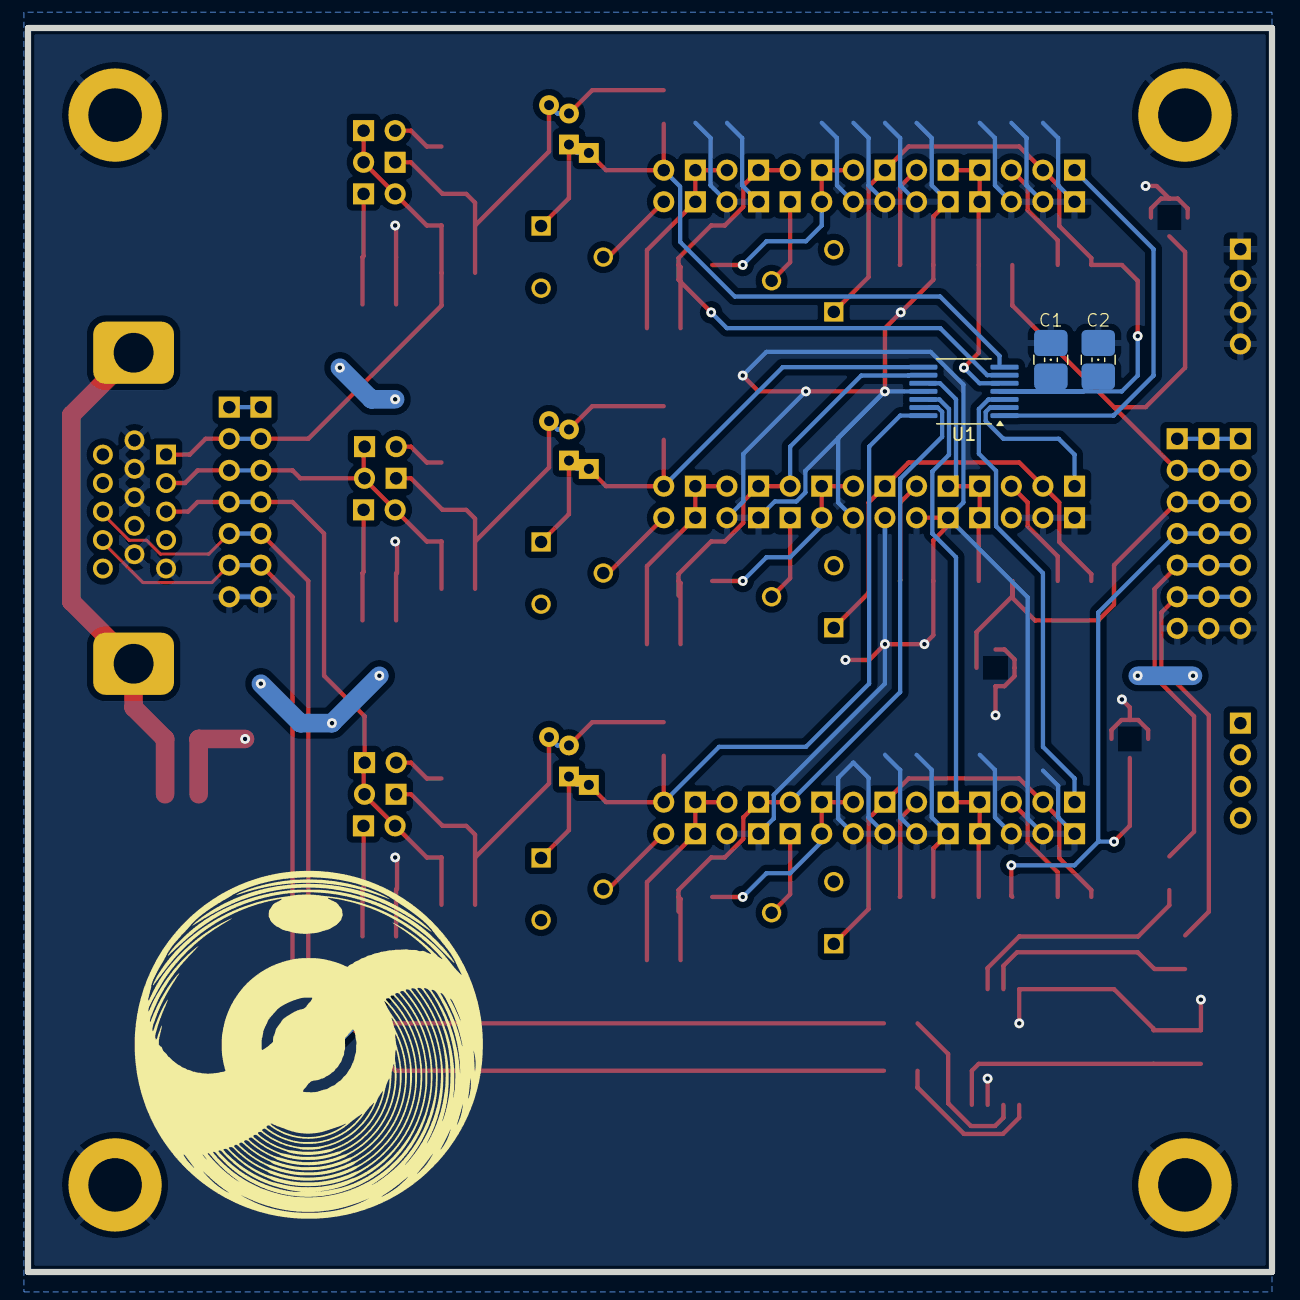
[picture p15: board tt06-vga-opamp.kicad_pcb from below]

Board: 2 copper layers, 100.0 x 100.0 mm, 117 parts (3 on the bottom side), 56 nets.

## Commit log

2024-04-03 Basic inverter schematic and symbol in xschem
    [inverter.sch]
2024-04-03 Adding basic testbench for inverter
    [tb_inverter.sch]
2024-04-03 Inverter testbench: Add Tiny Tapeout analog output load
    [tb_inverter.sch]
2024-04-03 Inverter 4x size; current graph in TB
    [inverter.sch, tb_inverter.sch]
2024-04-04 Change tb_inverter to Monte Carlo sim
    [tb_inverter.sch]
2024-04-04 Adding Magic layout for inverter cell
    [tb_inverter.sch]
2024-04-09 LVS works for inverter. Inverter parax sim added to tb_inverter
    [tb_inverter.sch]
2024-04-12 Progress on R2R DAC, and fix for integration DRC error. See: https://discord.com/channels/1009193568256135208/1162428058817540116/1228303318309142610
    [r2r.sch, tb_r2r.sch, tt06_analog_load.sch]
2024-04-17 Layout done for R2R DAC
    [r2r.sch, tb_r2r.sch]
2024-04-17 Change R2R to not use bus names for ports
    [r2r.sch, tb_r2r.sch]
2024-04-17 Put PEX into tb_r2r
    [tb_r2r.sch]
2024-04-18 Successful harden of controller block
    [pin_order.cfg]
2024-04-19 Wiring up controller and 3 DACs in top module. Pinout changed
2024-04-19 Modified and rehardened controller; progress on wiring it all up
    [pin_order.cfg]
2024-04-19 More progress on wiring
2024-04-19 Continuing wiring progress
2024-04-19 All wired up, I think
2025-01-28 Adding PCB design stuff
    [CONMHF1-SMD-G-T.step, EVN-D8AA03B55.step, OPA3355.DSN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]
2025-01-30 Partial layout of interposer PCB
    [tt06-vga-interposer.kicad_pcb, tt06-vga-interposer.kicad_sch]
2025-02-03 Nearly finished 1st draft of interposer PCB
    [tt06-vga-interposer.kicad_pcb, tt06-vga-interposer.kicad_sch]
2025-02-07 Interposer PCB: First complete version
    [tt06-vga-interposer.kicad_pcb, tt06-vga-interposer.kicad_sch]
2025-02-07 Interposer PCB: Rounded corners
    [tt06-vga-interposer.kicad_pcb]
2025-02-08 Interposer PCB: Thicken power traces, add final Gerbers
    [tt06-vga-interposer-B_Cu.gbl, tt06-vga-interposer-B_Mask.gbs, tt06-vga-interposer-B_Paste.gbp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]
2025-02-20 Fix sim for 40ns pixel time; add digital in graph
    [tb_r2r.sch]
2025-02-20 Tweak a few other parts of the sim and docs
    [tb_r2r.sch, tt06_analog_load.sch]
2025-02-23 Tidy up interposer schematic a little
    [tt06-vga-interposer.kicad_pcb, tt06-vga-interposer.kicad_sch]
2025-05-01 Fix PCB library path [no ci]
